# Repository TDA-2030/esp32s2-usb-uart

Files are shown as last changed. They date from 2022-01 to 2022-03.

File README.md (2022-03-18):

# ESP32S2-USB-UART



USB to UART board by ESP32-S2

## Feature

- [x] USB to UART
- [x] PCB size: 30mm x 14mm
- [x] All output with ESD protection
- [x] 3 LEDs
- [x] LEDs to indicate UART signal
- [x] 3.3V output
- [x] Either USBA or Type-C plug
- [ ] Auto download for ESP series chips
- [ ] Wireless connecting

## Pin definition

| 1(TCK) | 10(TX) |
| --- | --- |
| 2(TDI) | 9(RX)  |
| 3(TDO) | 8(EN)  |
| 4(TMS) | 7(IO0) |
| 5(3V3) | 6(GND) |

## Preview image

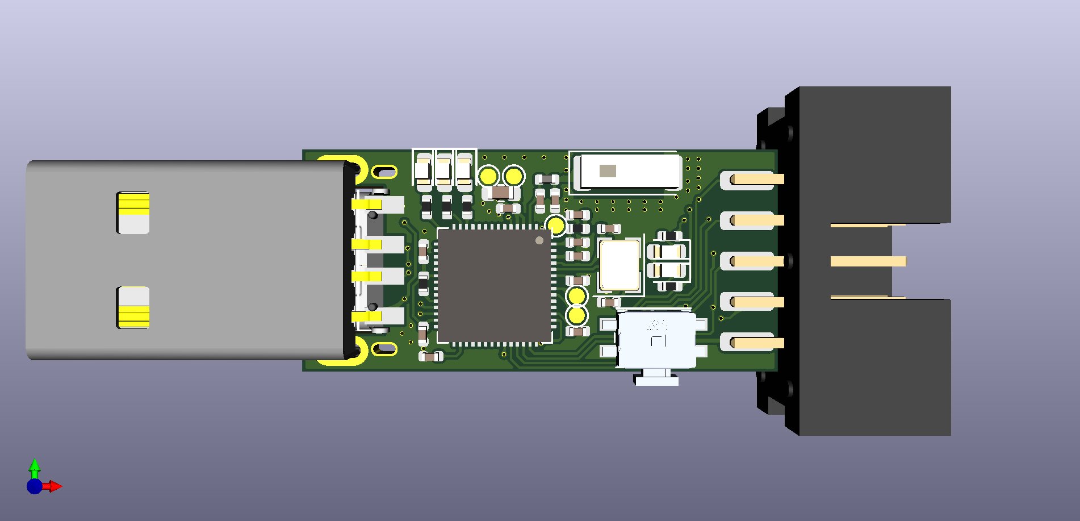
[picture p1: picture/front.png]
front


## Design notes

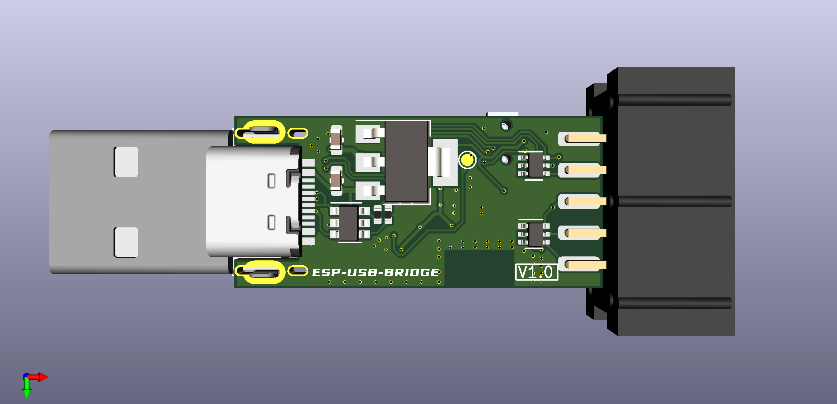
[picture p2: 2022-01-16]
picture/back.png

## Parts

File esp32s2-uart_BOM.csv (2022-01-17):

Comment | Description | Designator | Footprint | LibRef | Pins | Quantity | PartNumber | url
10uf | desc | C3, | C_0603_1608Metric | libref | 2 | 1
0.1uf | desc | C4,C5,C6,C7,C9,C11,C12,C13,C14, | C_0402_1005Metric | libref | 2 | 9
10pf | desc | C8,C10, | C_0402_1005Metric | libref | 2 | 2
TBD | desc | C15,C16, | C_0402_1005Metric | libref | 2 | 2
RED | desc | D1, | LED_0603_1608Metric | libref | 2 | 1
GREEN | desc | D2, | LED_0603_1608Metric | libref | 2 | 1
BLUE | desc | D3, | LED_0603_1608Metric | libref | 2 | 1
LED_YELLOW | desc | D10,D11, | LED_0603_1608Metric | libref | 2 | 2
Conn_02x05_Counter_Clockwise | desc | J3, | Header_2x5_pin | libref | 10 | 1
L | desc | L1, | L_0402_1005Metric | libref | 2 | 1
1k | desc | R3,R4,R5,R8,R9, | R_0402_1005Metric | libref | 2 | 5
10k | desc | R6,R7, | R_0402_1005Metric | libref | 2 | 2
ESP32-S2FH4 | desc | U3, | QFN-56-1EP_7x7mm_P0.4mm_EP5.6x5.6mm | libref | 73 | 1
Crystal_GND24_Small | desc | Y1, | Crystal_SMD_EuroQuartz_MT-4Pin_3.2x2.5mm | libref | 4 | 1
Antenna_Chip | desc | AE1, | Johanson_2450AT43F0100 | libref | 2 | 1
TestPoint | desc | TP1,TP2,TP4,TP5,TP6, | TestPoint_Pad_D1.0mm | libref | 1 | 5
10uf | desc | C1,C2, | C_0603_1608Metric | libref | 2 | 2
PESD5V0L5UY | desc | D4,D5, | SOT-363_SC-70-6 | libref | 6 | 2
22 | desc | R1,R2, | R_0402_1005Metric | libref | 2 | 2
5.1k | desc | R10,R11, | R_0402_1005Metric | libref | 2 | 2
AMS1117-3.3 | desc | U1, | SOT-223-3_TabPin2 | libref | 4 | 1
USBLC6-2SC6 | desc | U2, | SOT-23-6 | libref | 6 | 1
TestPoint | desc | TP3, | TestPoint_Pad_D1.0mm | libref | 1 | 1
logo | desc | logo1, | ESP-USB-Bridge | libref | 0 | 1
Through Hole Items
USB_A | desc | J1, | USB_A_CNCTech_1001-011-01101_Horizontal | libref | 8 | 1
SW_Push | desc | SW1, | button | libref | 6 | 1
USB_C_Receptacle_USB2.0 | desc | J2, | USB_C_Receptacle | libref | 20 | 1

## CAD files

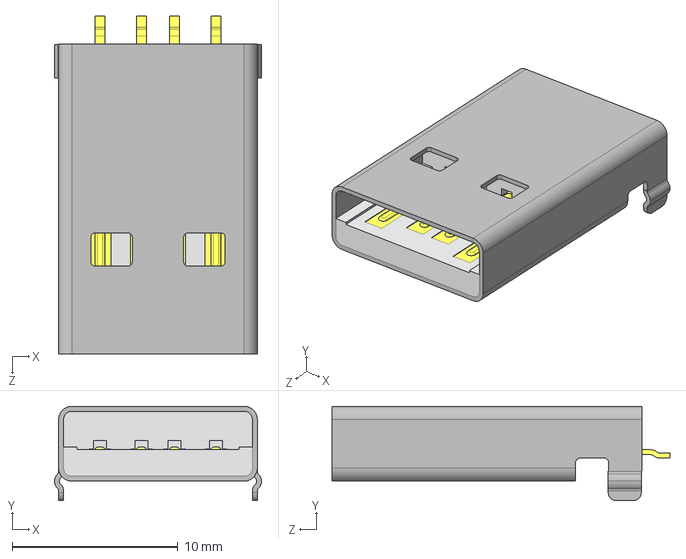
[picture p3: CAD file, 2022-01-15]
kicad-libraries/3d/USB-AM-S-F-B-TH.STEP
12.5 x 5.70 x 20.4 mm

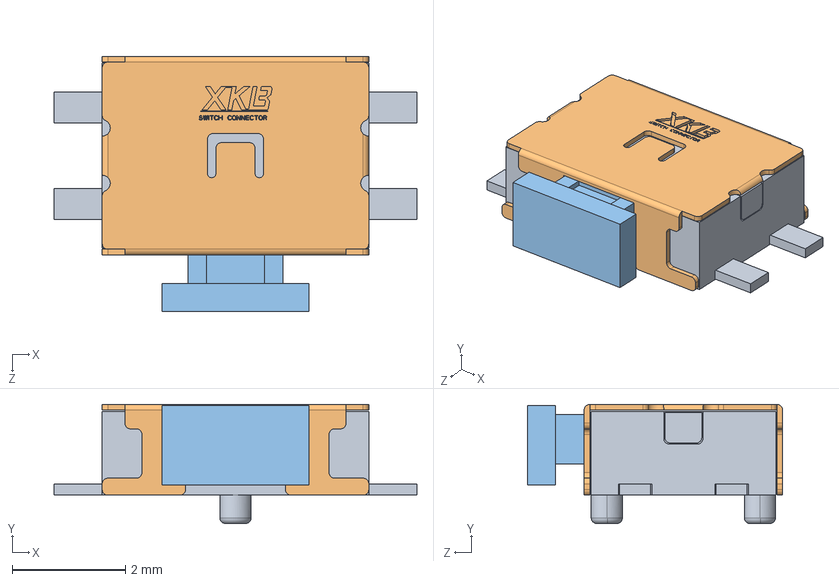
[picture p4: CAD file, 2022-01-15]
kicad-libraries/3d/ts-1186d-c-a.STEP
6.40 x 2.10 x 4.50 mm
ts-1186d-c-a_01
ts-1186d-c-a_02
ts-1186d-c-a_03

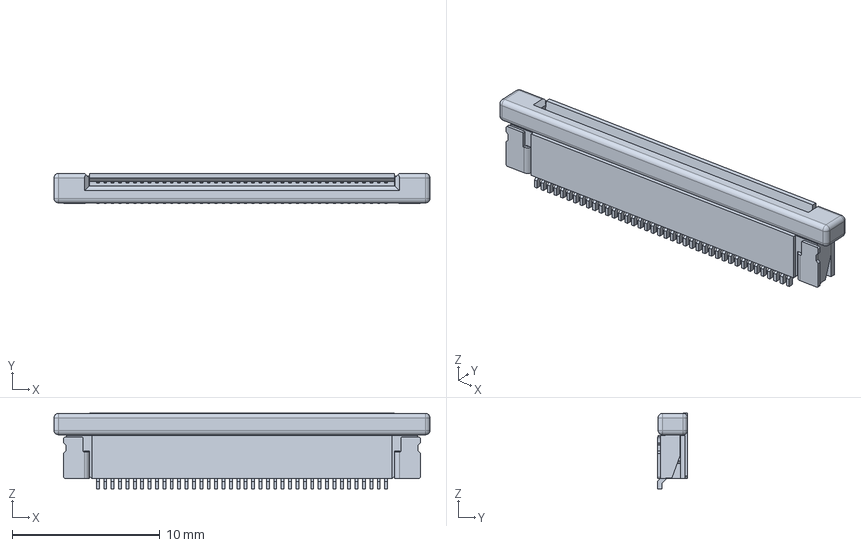
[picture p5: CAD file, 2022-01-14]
kicad-libraries/3d/c-4-1734839-0-c-3d.stp
25.4 x 2.05 x 5.11 mm

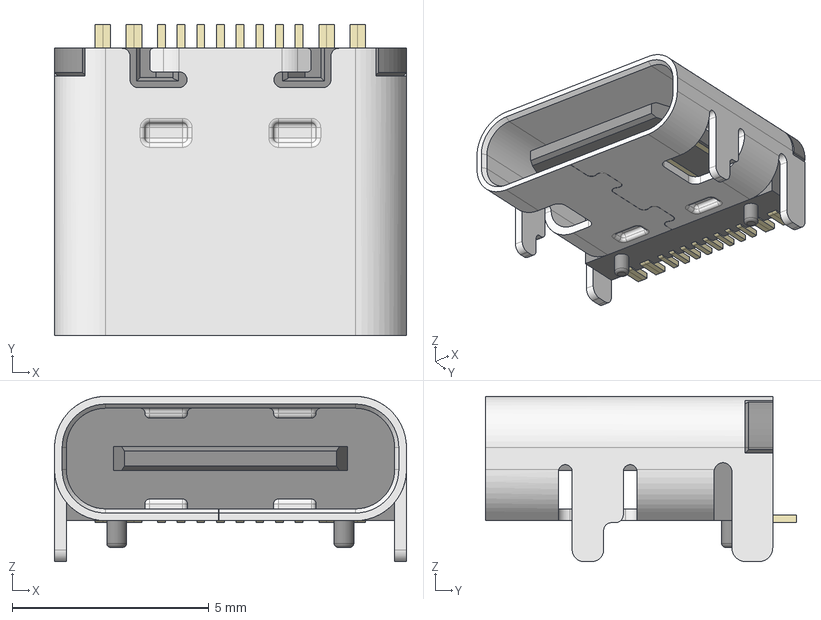
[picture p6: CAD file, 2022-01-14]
kicad-libraries/3d/HRO_TYPE-C-31-M-12.step
8.95 x 7.90 x 4.20 mm

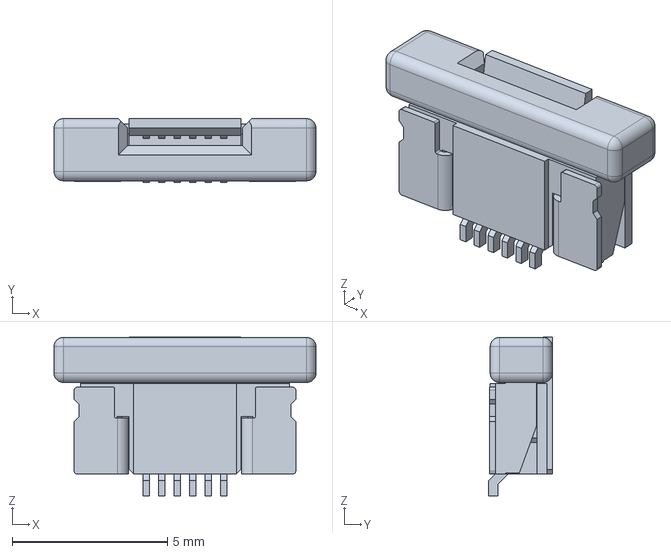
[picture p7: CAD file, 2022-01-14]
kicad-libraries/3d/c-1734839-6-c-3d.stp
8.43 x 2.05 x 5.11 mm

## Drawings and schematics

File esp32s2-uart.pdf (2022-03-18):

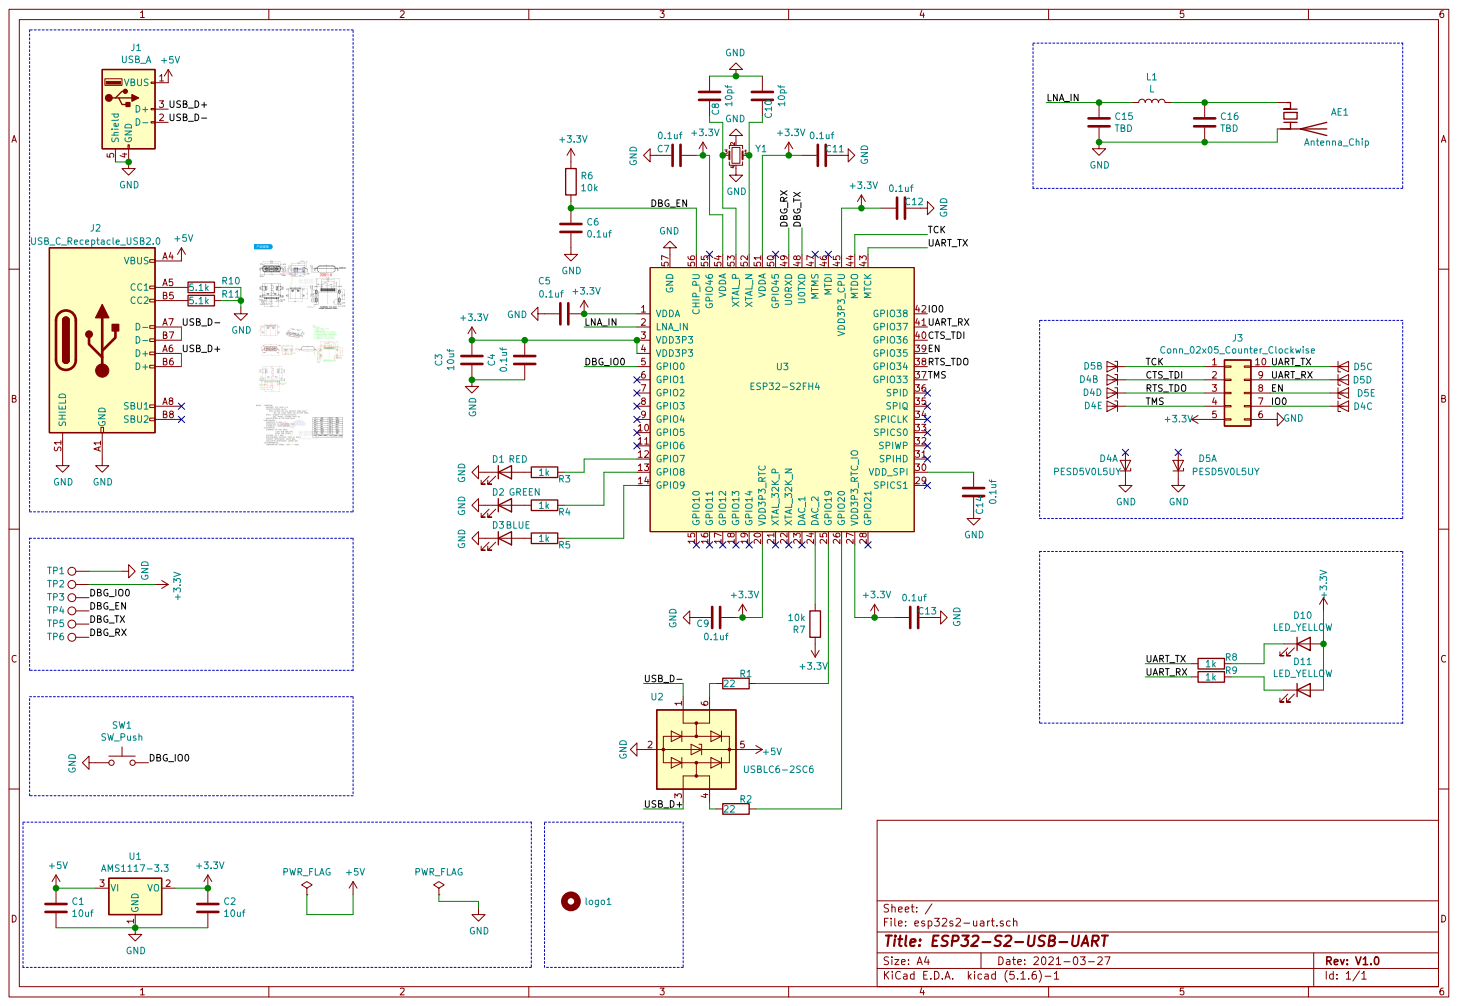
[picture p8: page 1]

1 VO 2 VI 3 U1 AMS1117-3.3 GND A1 VBUS A4 CC1 A5 D+ A6 D- A7 SBU1 A8 CC2 B5 D+ B6 D- B7 SBU2 B8 SHIELD S1

File: esp32s2-uart.sch Sheet: /
Id: 1/1 Title: ESP32-S2-USB-UART

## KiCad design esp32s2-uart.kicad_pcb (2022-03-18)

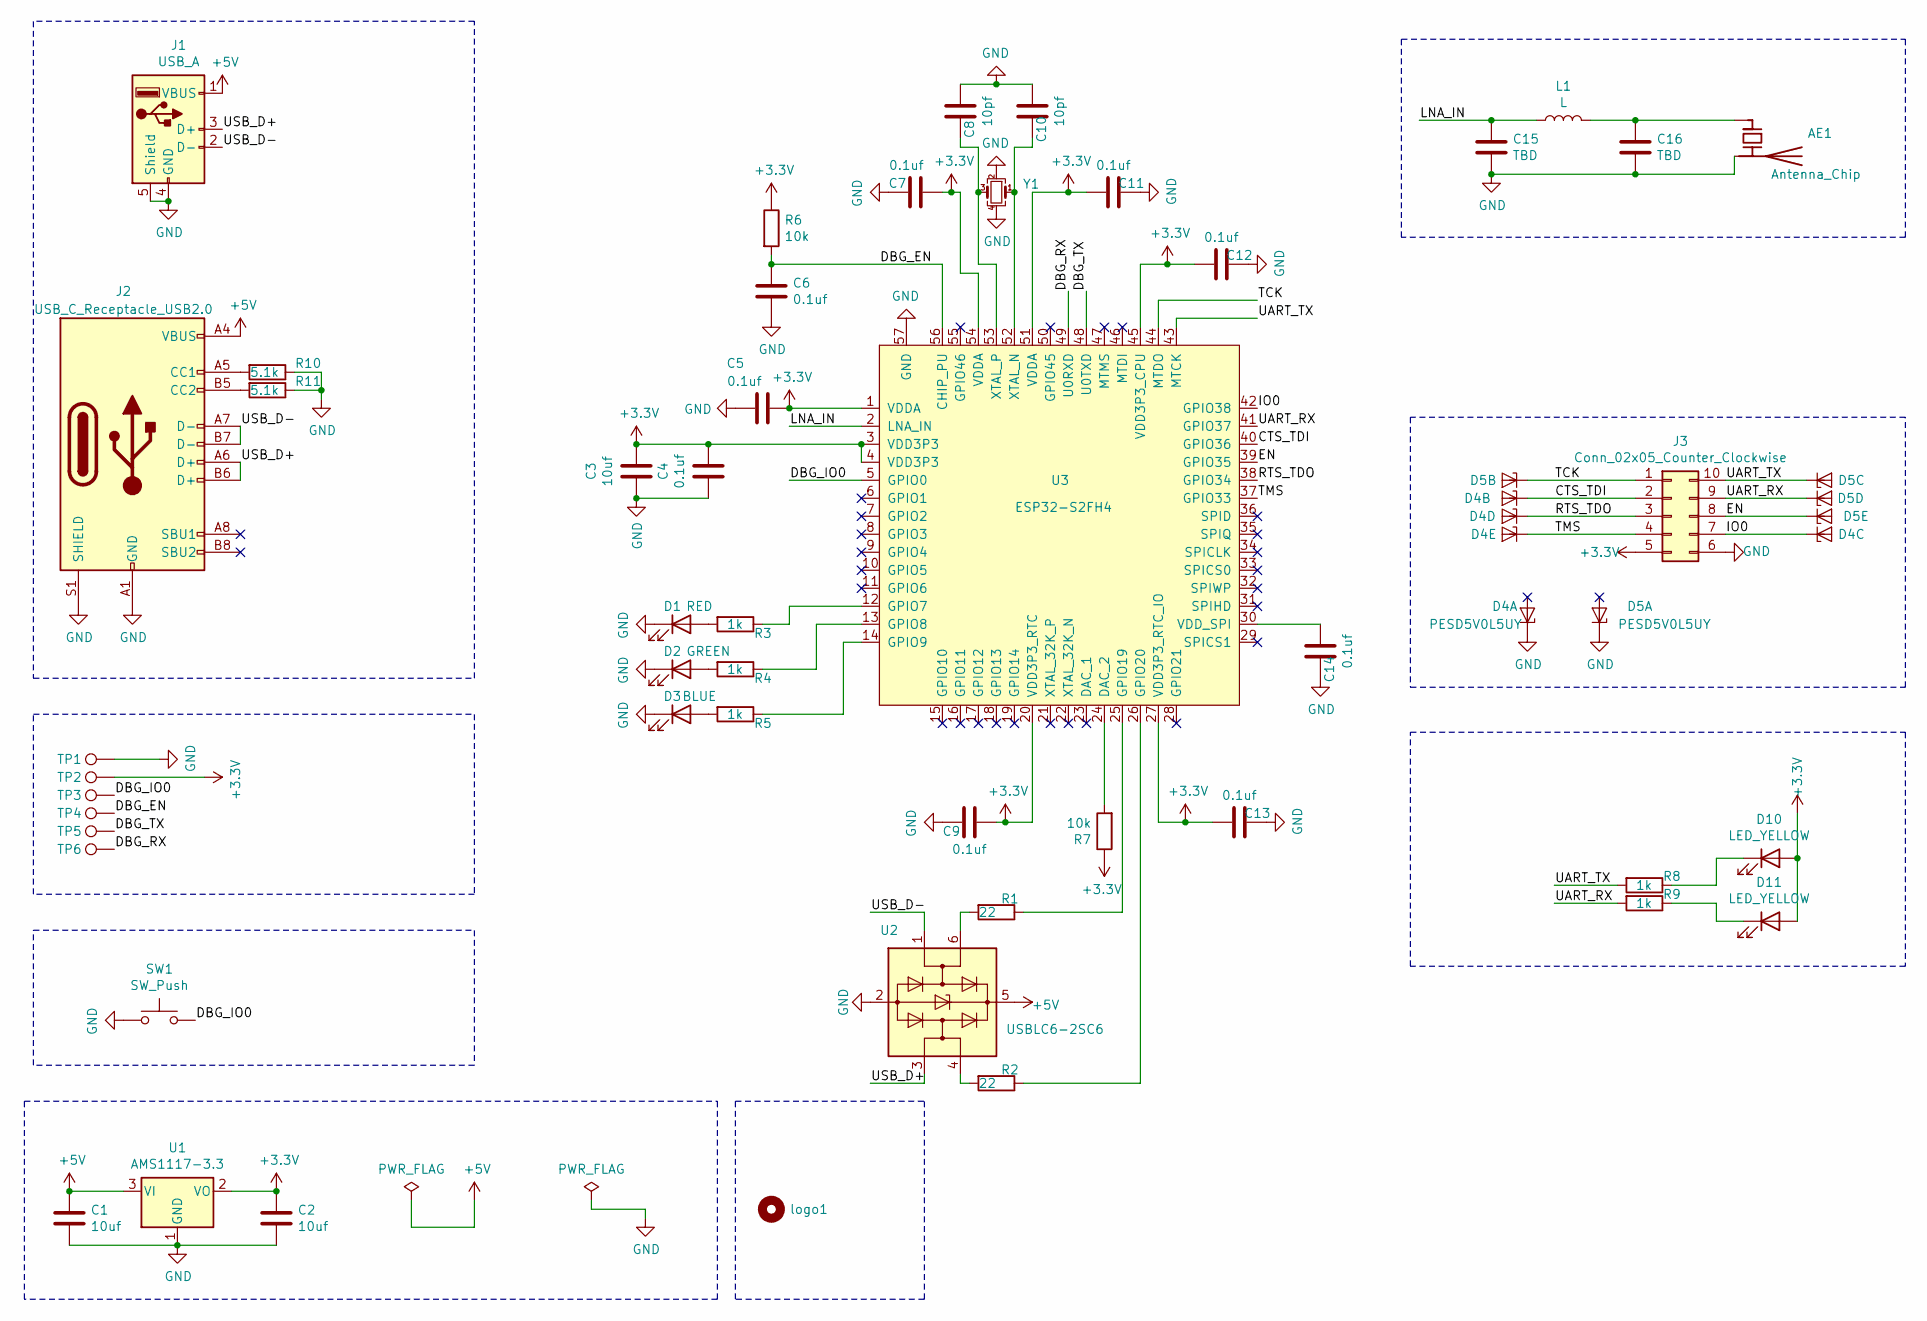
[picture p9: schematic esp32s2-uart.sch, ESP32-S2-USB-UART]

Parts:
AE1: Antenna_Chip; Johanson_2450AT43F0100
C1, C2, C3: 10uf; C_0603_1608Metric
C4, C5, C6, C7, C9, C11, C12, C13, C14: 0.1uf; C_0402_1005Metric
C8, C10: 10pf; C_0402_1005Metric
C15, C16: TBD; C_0402_1005Metric
D1: RED; LED_0603_1608Metric
D2: GREEN; LED_0603_1608Metric
D3: BLUE; LED_0603_1608Metric
D4, D5: PESD5V0L5UY; SOT-363_SC-70-6
D10, D11: LED_YELLOW; LED_0603_1608Metric
J1: USB_A; USB_A_CNCTech_1001-011-01101_Horizontal
J2: USB_C_Receptacle_USB2.0; USB_C_Receptacle
J3: Conn_02x05_Counter_Clockwise; Header_2x5_pin
L1: L; L_0402_1005Metric
R1, R2: 22; R_0402_1005Metric
R3, R4, R5, R8, R9: 1k; R_0402_1005Metric
R6, R7: 10k; R_0402_1005Metric
R10, R11: 5.1k; R_0402_1005Metric
SW1: SW_Push; button
TP1, TP2, TP3, TP4, TP5, TP6: TestPoint; TestPoint_Pad_D1.0mm
U1: AMS1117-3.3; SOT-223-3_TabPin2
U2: USBLC6-2SC6; SOT-23-6
U3: ESP32-S2FH4; QFN-56-1EP_7x7mm_P0.4mm_EP5.6x5.6mm
Y1: Crystal_GND24_Small; Crystal_SMD_EuroQuartz_MT-4Pin_3.2x2.5mm
logo1: logo; ESP-USB-Bridge

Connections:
+3V3: C2.2, C3.1, C4.1, C5.1, C7.1, C9.2, C11.2, C12.2, C13.2, D10.2 (A), D11.2 (A), J3.5, R6.1, R7.1, TP2.1, U1.2 (VO), U3.1 (VDDA), U3.3 (VDD3P3), U3.4 (VDD3P3), U3.20 (VDD3P3_RTC), U3.27 (VDD3P3_RTC_IO), U3.45 (VDD3P3_CPU), U3.51 (VDDA), U3.54 (VDDA)
+5V: C1.2, J1.1 (VBUS), J2.A4 (VBUS), J2.A9 (VBUS), J2.B4 (VBUS), J2.B9 (VBUS), U1.3 (VI), U2.5 (VBUS)
/CTS_TDI: D4.3 (K2), J3.2, U3.40 (GPIO36)
/DBG_EN: C6.1, R6.2, TP4.1, U3.56 (CHIP_PU)
/DBG_IO0: SW1.2, TP3.1, U3.5 (GPIO0)
/DBG_RX: TP6.1, U3.49 (U0RXD)
/DBG_TX: TP5.1, U3.48 (U0TXD)
/EN: D5.6 (K5), J3.8, U3.39 (GPIO35)
/IO0: D4.4 (K3), J3.7, U3.42 (GPIO38)
/LNA_IN: C15.1, L1.1, U3.2 (LNA_IN)
/RTS_TDO: D4.5 (K4), J3.3, U3.38 (GPIO34)
/TCK: D5.3 (K2), J3.1, U3.44 (MTDO)
/TMS: D4.6 (K5), J3.4, U3.37 (GPIO33)
/UART_RX: D5.5 (K4), J3.9, R9.2, U3.41 (GPIO37)
/UART_TX: D5.4 (K3), J3.10, R8.2, U3.43 (MTCK)
/USB_D+: J1.3 (D+), J2.A6 (D+), J2.B6 (D+), U2.3 (I/O2)
/USB_D-: J1.2 (D-), J2.A7 (D-), J2.B7 (D-), U2.1 (I/O1)
GND: AE1.2 (PCB_Trace), C1.1, C2.1, C3.2, C4.2, C5.2, C6.2, C7.2, C8.2, C9.1, C10.2, C11.1, C12.1, C13.1, C14.1, C15.2, C16.2, D1.1 (K), D2.1 (K), D3.1 (K), D4.1 (K1), D5.1 (K1), J1.4 (GND), J1.5 (Shield), J2.A1 (GND), J2.A12 (GND), J2.B1 (GND), J2.B12 (GND), J2.S1 (SHIELD), J3.6, R10.1, R11.1, SW1.1, TP1.1, U1.1 (GND), U2.2 (GND), U3.57 (GND), Y1.2, Y1.4
unnamed: AE1.1 (FEED), C16.1, L1.2
unnamed: C8.1, U3.53 (XTAL_P), Y1.3
unnamed: C10.1, U3.52 (XTAL_N), Y1.1
unnamed: C14.2, U3.30 (VDD_SPI)
unnamed: D1.2 (A), R3.2
unnamed: D2.2 (A), R4.2
unnamed: D3.2 (A), R5.2
unnamed: D10.1 (K), R8.1
unnamed: D11.1 (K), R9.1
unnamed: J2.A5 (CC1), R10.2
unnamed: J2.B5 (CC2), R11.2
unnamed: R1.1, U3.25 (GPIO19)
unnamed: R1.2, U2.6 (I/O1)
unnamed: R2.1, U3.26 (GPIO20)
unnamed: R2.2, U2.4 (I/O2)
unnamed: R3.1, U3.12 (GPIO7)
unnamed: R4.1, U3.13 (GPIO8)
unnamed: R5.1, U3.14 (GPIO9)
unnamed: R7.2, U3.24 (DAC_2)

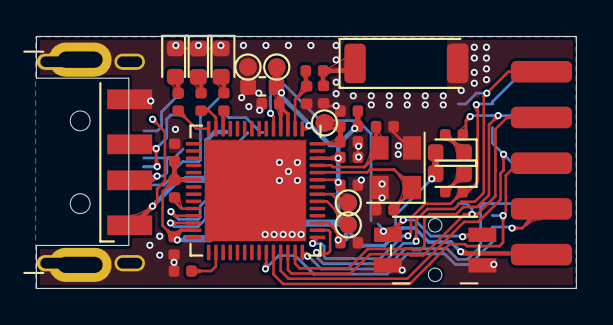
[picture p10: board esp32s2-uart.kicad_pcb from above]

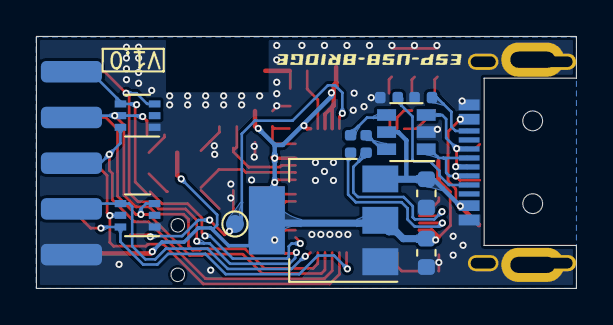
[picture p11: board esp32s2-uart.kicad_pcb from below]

Board: 2 copper layers, 30.0 x 14.0 mm, 51 parts (13 on the bottom side), 37 nets.

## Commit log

2021-03-26 add esp32-s2fh4 symbol lib
    [esp32s2-uart.sch]
2021-03-29 complete schematic
    [USB_Type_C_6pin.STEP, esp32s2-uart.sch]
2022-01-17 add type-c pull-down resistors
    [esp32s2-uart-Bottom_Cu.gbr, esp32s2-uart-Bottom_Mask.gbr, esp32s2-uart-Bottom_Paste.gbr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]
